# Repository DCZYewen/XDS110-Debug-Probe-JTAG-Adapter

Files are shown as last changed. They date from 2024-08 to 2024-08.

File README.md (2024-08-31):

# XDS110-Debug-Probe-JTAG-Adapter
JTAG Adapter board for TI-20 JTAG header.

这是一个将TI-20 JTAG接口转接为TI-14、ARM Cortex Debug 10P、ARM Serial Wire Debug and XH2.54 UART Jack.

由于一些在设计时没考虑到的线序问题，如果您需要使用常用的IDC 20Pin JTAG排线，请将TI-20 JTAG接口的简牛插座焊接在反面如图所示。

该转接板已在Texas Instrument Code Composer Studio 和 Keil MDK 和 VisualGDB环境下测试通过，可以正常仿真目标器件。

如果对DIY 一个XDS110探针刚兴趣，可以移步[OSHWHub](https://oshwhub.com/dczyewen/xds110-debug-probe)，制作您自己的XDS110探针。该设计具有标准的TI-20 JTAG Header， 可以仿真绝大多数ARM内核处理器以及TI DSP、mmWave Soc、 Wireless Socs。 详情请见[TI的产品手册](https://software-dl.ti.com/ccs/esd/documents/xdsdebugprobes/emu_xds110.html)。

## 效果图
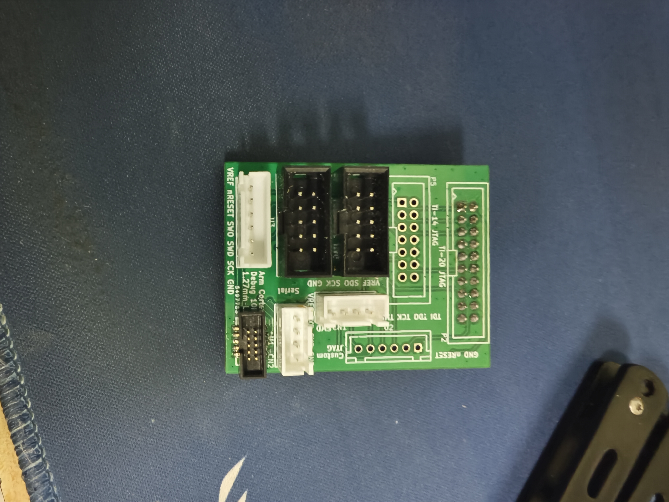
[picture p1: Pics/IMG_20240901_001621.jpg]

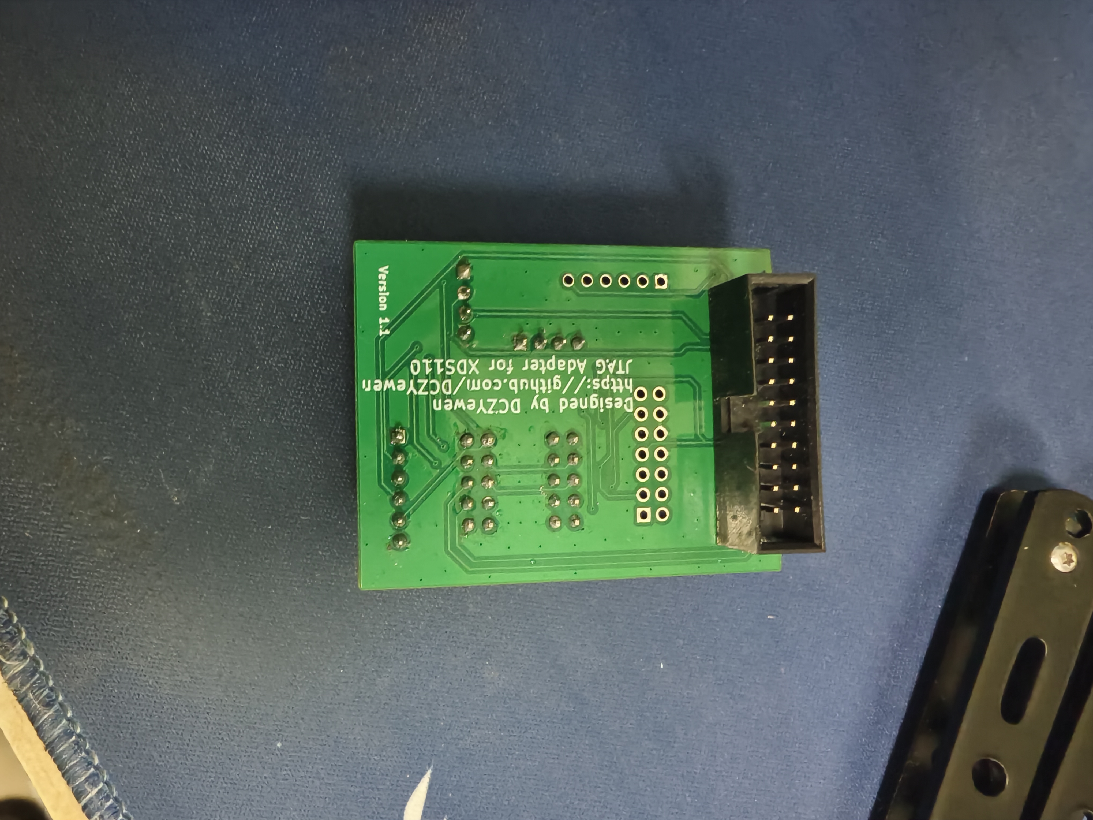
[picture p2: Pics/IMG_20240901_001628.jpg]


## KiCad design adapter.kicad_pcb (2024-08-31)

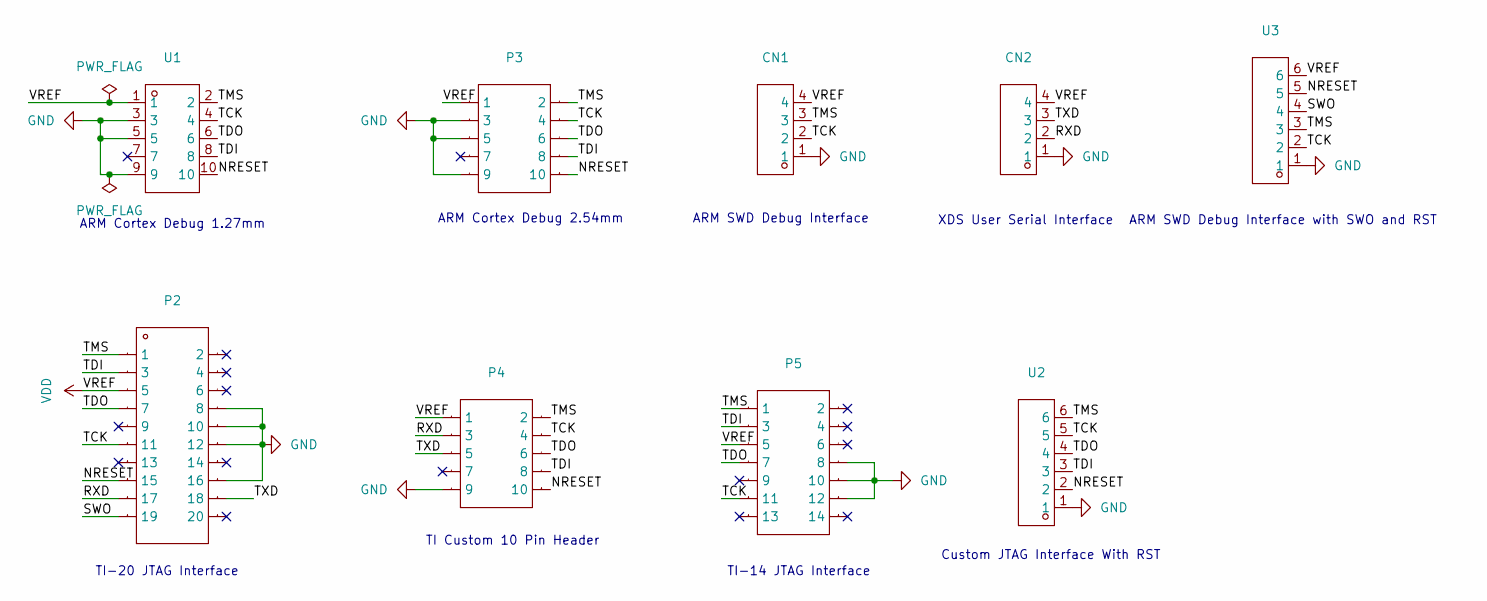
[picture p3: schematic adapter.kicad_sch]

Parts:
CN1, CN2: CONN-TH_4P-P2.50_4PIN; Manufacturer Part ZX-XH2.54-4PZZ; LCSC Part Name ZX-XH2.54-4PZZ
P2: IDC-TH_20P-P2.54-V-R2-C10-S2.54; Manufacturer Part 2.54-2*10P简牛; LCSC Part Name 2.54mm 排数:2
P3, P4: IDC-TH_10P-P2.54_C5665; Manufacturer Part 2.54-2*5P简牛; LCSC Part Name 2.54mm 2x5P 排数:2 每排P数:5
P5: IDC-TH_14P-P2.54-V-R2-C7-S2.54; Manufacturer Part 2.54-2*7P简牛; LCSC Part Name 2.54mm 2x7P 排数:2 每排P数:7
U1: CONN-SMD_5P-P1.27_IDC1.27-US2S-5A; Manufacturer Part IDC1.27-US2S-5A; LCSC Part Name 间距1.27 双排 贴片 双向垂直 2*5P 简牛
U2, U3: CONN-TH_6P-P2.50_ZX-XH2.54-6PZZ; Manufacturer Part ZX-XH2.54-6PZZ; LCSC Part Name ZX-XH2.54-6PZZ

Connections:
/NRESET: P2.15, P3.10, P4.10, U1.10, U2.2, U3.5
/RXD: CN2.2, P2.17, P4.3
/SWO: P2.19, U3.4
/TCK: CN1.2, P2.11, P3.4, P4.4, P5.11, U1.4, U2.5, U3.2
/TDI: P2.3, P3.8, P4.8, P5.3, U1.8, U2.3
/TDO: P2.7, P3.6, P4.6, P5.7, U1.6, U2.4
/TMS: CN1.3, P2.1, P3.2, P4.2, P5.1, U1.2, U2.6, U3.3
/TXD: CN2.3, P2.18, P4.5
GND: CN1.1, CN2.1, P2.8, P2.10, P2.12, P2.16, P3.3, P3.5, P3.9, P4.9, P5.8, P5.10, P5.12, U1.3, U1.5, U1.9, U2.1, U3.1
VDD: CN1.4, CN2.4, P2.5, P3.1, P4.1, P5.5, U1.1, U3.6

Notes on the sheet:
Custom JTAG Interface With RST
TI-20 JTAG Interface
TI-14 JTAG Interface
ARM SWD Debug Interface with SWO and RST
ARM SWD Debug Interface
ARM Cortex Debug 1.27mm
ARM Cortex Debug 2.54mm
XDS User Serial Interface
TI Custom 10 Pin Header

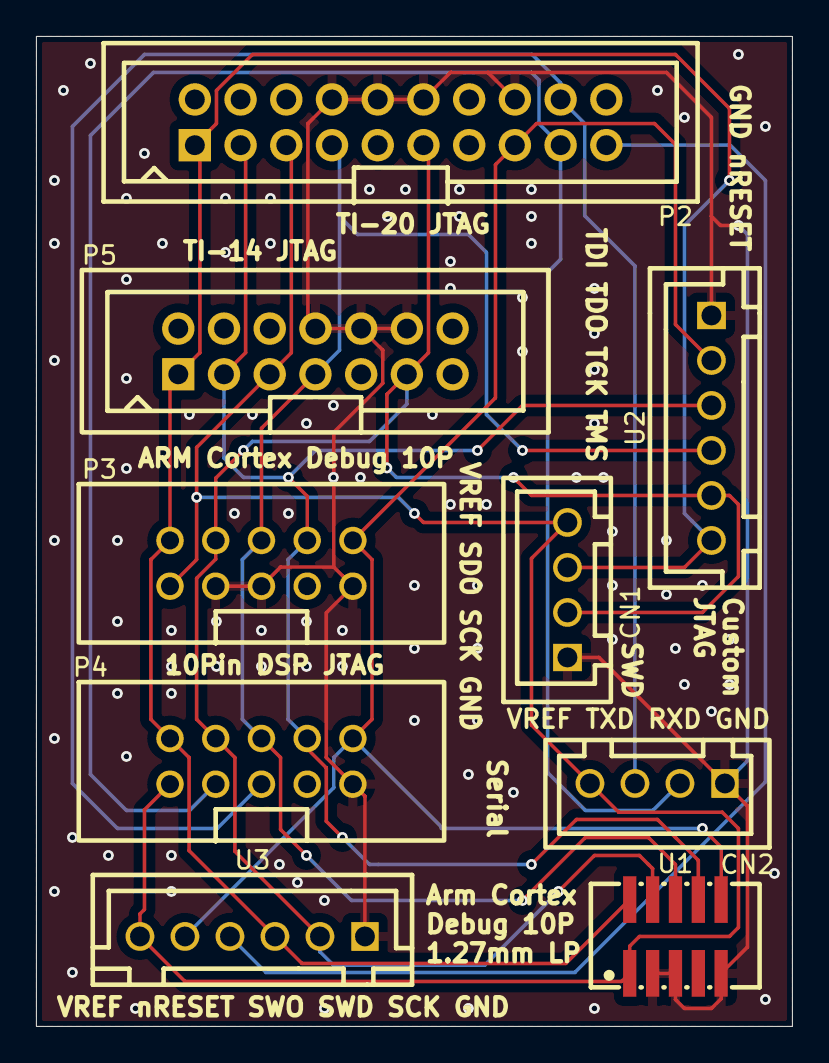
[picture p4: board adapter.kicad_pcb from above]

Board: 2 copper layers, 42.0 x 55.0 mm, 9 parts (0 on the bottom side), 10 nets.
